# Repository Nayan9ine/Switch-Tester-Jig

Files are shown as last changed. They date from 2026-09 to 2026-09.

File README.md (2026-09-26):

# Switch-Tester-Jig
<div align="right"><i>-by Nayan Ag</i></div>
<br>
Created a switch testing jig using Arduino UNO which tests the electrical durability of contact in scooty switches. 
<br><br>
This is a project that I created during my internship in a 2 wheeler EV startup company. The handle-bar switch assembly are fitted by various switches that the company imports from different vendors. Since it's a startup company we experimented by ordering from different vendors for the same switch. This project was made to test the durability of those.
<br><br>
The various types of switches that were tested are: Horn, Upper-Dipper, Ignition, Reverse.
<br>
Components used: A switch and motor holder,L298N motor controller, two 16X2 I2C LCD, arduino uno, jumper cables,cam to press the button, Switch coupler,12v battery to run motor, Switch for manual control.
<br>
The cam and holder for switches was made by senior.
<br><br>
<table>
  <tr>
    <td>jig
    <br>  <div  align="center"><sub><i> Fig1:Jig with cam and switch installed</i></sub></div>
</td>
    <td>motor holder
    <br>  <div  align="center"><sub><i> Fig2:motor fitting location</i></sub></div>
</td>
    <td>jig switch coupler
    <br><div align="center"><sub><i> Fig3:back side</i></sub></div>
</td>
  </tr>
</table>
<br><br>
<table>
  <tr>
    <td>arduino
    <br>  <div  align="center"><sub><i> Fig4:Arduino UNO</i></sub></div>
</td>
    <td>2 lcds
    <br>  <div  align="center"><sub><i> Fig5:2 LCDs</i></sub></div>
</td>
    <td>battery and switch
    <br><div align="center"><sub><i> Fig6:12v Battery & ON-OFF Switch for manual control</i></sub></div>
</td>
  </tr>
</table>
<br>
<table>
  <tr>
    <td>L298N motor controller
    <br>  <div  align="center"><sub><i> Fig7:Arduino UNO</i></sub></div>
</td>
    <td>switches
    <br>  <div  align="center"><sub><i> Fig8:Switches</i></sub></div>
</td>
    <td>12v motor
    <br><div align="center"><sub><i> Fig9:12v DC Motor</i></sub></div>
</td>
  </tr>
</table>
<br>
<table>
  <tr>
    <td>Switch Pinout
    <br>  <div  align="center"><sub><i> Fig10:Switch Pinout</i></sub></div>
</td>
    <td>overall setup
    <br>  <div  align="center"><sub><i> Fig11:Overall Setup</i></sub></div>
</td>
  </tr>
</table>
<br><br>
Drive link for working video: https://drive.google.com/drive/folders/12oiliMJjxmbsB1hyvkpnEl2Vyk8v8IB5?usp=sharing
<br><br>
<table>
  <tr>
    <td>Sch ERC check
  <br>  <div  align="center"><sub><i> Fig12:Schematic with ERC</i></sub></div>
</td>
    <td>DRC PCB editor Switch Test Jig
    <br>  <div  align="center"><sub><i> Fig13:PCB editor DRC check</i></sub></div>
</td>
    <td>Switch Test Jig PCB editor
    <br>  <div  align="center"><sub><i> Fig14:PCB editor Full view</i></sub></div>
</td>
  </tr>
</table>
<br>
<table>
  <tr>
    <td>3d front switch test
  <br>  <div  align="center"><sub><i> Fig15:3D Front</i></sub></div>
</td>
    <td>3d side switch test
    <br>  <div  align="center"><sub><i> Fig16:3D Side</i></sub></div>
</td>
    <td>3d back switch test
    <br>  <div  align="center"><sub><i> Fig17:3D Back</i></sub></div>
</td>
  </tr>
</table>

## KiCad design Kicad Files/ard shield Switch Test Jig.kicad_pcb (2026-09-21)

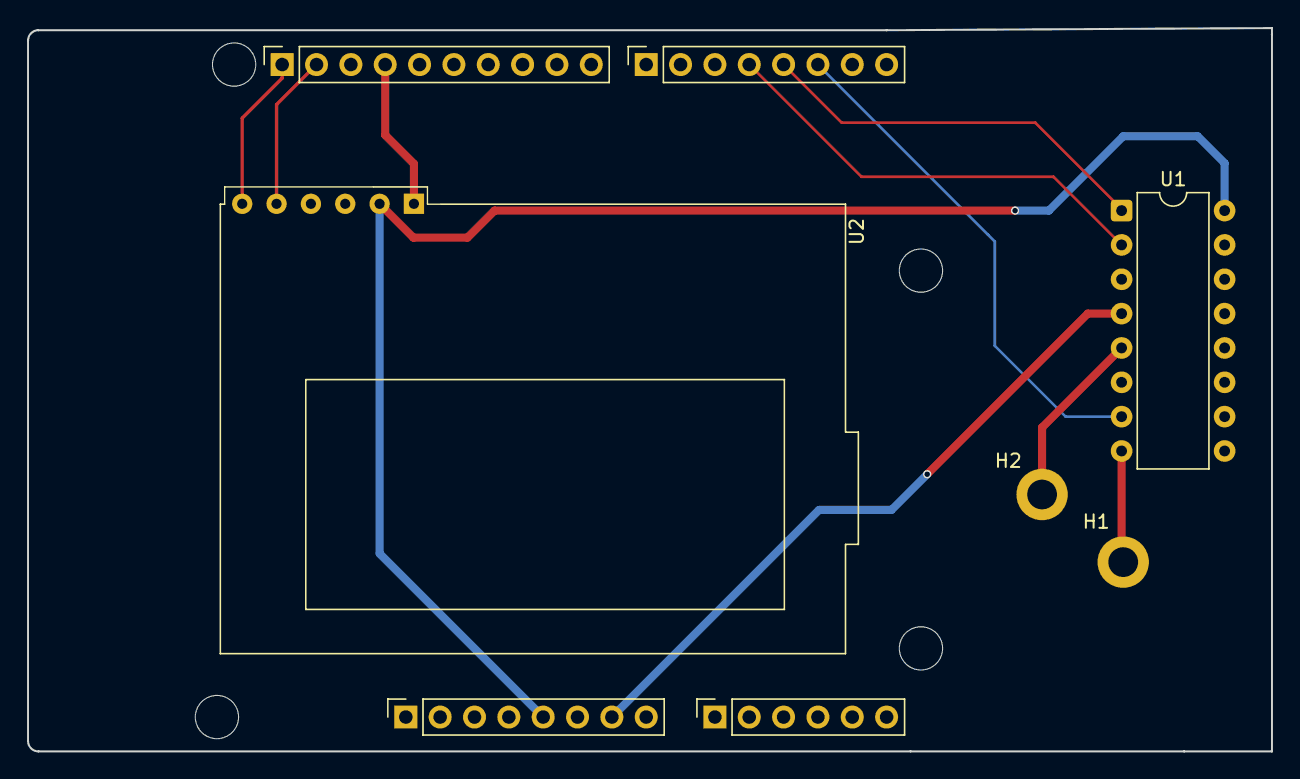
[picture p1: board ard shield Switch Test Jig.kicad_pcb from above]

Board: 2 copper layers, 92.0 x 53.5 mm, 12 parts (0 on the bottom side), 10 nets.

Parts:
H1: +12v; MountingHole_2.2mm_M2_DIN965_Pad
H2: 0v; MountingHole_2.2mm_M2_DIN965_Pad
J1: Power; PinSocket_1x08_P2.54mm_Vertical
J2: Digital/PWM; PinSocket_1x10_P2.54mm_Vertical
J3: Analog; PinSocket_1x06_P2.54mm_Vertical
J4: Digital/PWM; PinSocket_1x08_P2.54mm_Vertical
MH1, MH2, MH3, MH4: MountingHole_3.2mm
U1: L293D; DIP-16_W7.62mm
U2: EA_T123X-I2C

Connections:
/2: J4.6, U1.7 (2A)
/4: J4.4, U1.2 (1A)
/5v: J1.5, U1.16 (VCC1), U2.2 (VDD)
/*3: J4.5, U1.1 (EN1,2)
/SCL/A5: J2.1, U2.6 (SCL)
/SDA/A4: J2.2, U2.5 (SDA)
GND: J1.7, U1.4 (GND)
GND2: J2.4, U2.1 (VSS)
unnamed: H2.1, U1.5 (GND)
unnamed: H1.1, U1.8 (VCC2)

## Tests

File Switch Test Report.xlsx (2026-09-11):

Switch Test Report
Report No: |  |  | Report Date: |  | 2024-04-08
Report Revision |  | 1 | Prepared By: |  | Nayan
Subject | Endurance testing of Switch
Objective | Testing the number of times the switch works properly till failure
Test Procedure Detail
A switch is put in the testing jig and the switches are pressed at frequency of 10,814 for Horn and 11064 for upper/dipper per hour and Horn and up/dip was run for 12 hrs whereas reverse was run for 10 hrs. As soon as the number of clicks surpassed the target the test was considered to be successful.
SWITCH TYPE |  | VENDOR NAME |  | USAGE
Upper-Dipper |  |  |  | Used to change headlight beam direction -Upper mode used in long range to increase visibility -Dipper mode used to avoid glaring
Horn |  |  |  | Auditory warning to alert the other vehicles of your presence
Reverse |  |  |  | Used to put the vehicle in reverse mode
MODE 1 |  |  |  | ECO mode
MODE 3 |  |  |  | POWER mode
TARGET: 1lakh clicks per switch
Observation/Result
SWITCH |  | NO. OF CLICKS |  | FREQUENCY (per hr) |  | REMARK
Horn |  | 1,32,841 |  | 10814 |  | parameters met
Upper |  | 89573 |  | 11064 |  | switch stopped responding to machine press as it's connections became soft but still works when pressed manually
Dipper |  | 1,32,724 |  | 16393 |  | Parameters met
Reverse |  | 1,24,047 |  | 12570 |  | parameters met
Mode 3 |  | 54216 |  | 5672 |  | Switch deformed but still works (not workable with jig)
Mode 1 |  | 40999 |  | 4795
OFF
DRL
HI-BEAM
CONCLUSION
The testing of the switch was done and the required goal parameters were succesfully met with the exception of upper switch. and mode switch

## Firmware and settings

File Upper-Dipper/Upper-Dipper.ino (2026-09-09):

#include <Wire.h>
#include <LiquidCrystal_I2C.h>

//L298N MOTOR DRIVER pins
#define enA 5
#define in1 2
#define in2 3

//upper switch
const byte switchPin1 = 4;
//variables needed to detect switch press
byte switchState1 = LOW;
byte lastSwitchState1 = LOW;
unsigned long counter1 = 0;              //stores switch press number
unsigned long lastDebounceTime1 = 0;
unsigned long debounceDelay1 = 50;
//variables needed for flashing function
unsigned long lastCounterChangeTime1 = 0;
unsigned long flashingInterval1 = 5000;  // Set the interval for flashing in milliseconds

//dipper switch
const byte switchPin2 = 6;  
byte switchState2 = LOW;
byte lastSwitchState2 = LOW;
unsigned long counter2 = 0;
unsigned long lastDebounceTime2 = 0;
unsigned long debounceDelay2 = 50;
unsigned long lastCounterChangeTime2 = 0;
unsigned long flashingInterval2 = 5000;  

//LCD initialization
LiquidCrystal_I2C lcd(0x27, 16, 2);
//by deafult not flashing
bool isFlashing1 = false;
bool isFlashing2 = false;
unsigned long lastFlashTime1 = 0;
unsigned long lastFlashTime2 = 0;

void setup() {
  lcd.init();
  lcd.setBacklight(255);
  lcd.print("Up : ");
  lcd.setCursor(0, 1);
  lcd.print("Dip: ");
  // Serial.begin(9600);
  /*Using digital pin as INPUT makes arduino connect that pin to a large resistor value so it takes very minimal current,
  hence no risk of pin burning*/
  pinMode(switchPin1, INPUT);
  pinMode(switchPin2, INPUT);
  //motor config
  pinMode(enA, OUTPUT);
  pinMode(in1, OUTPUT);
  pinMode(in2, OUTPUT);
  // pinMode(button, INPUT);
  // Set initial rotation direction =stopped
  pinMode(in1,LOW);
  pinMode(in2,LOW);
  analogWrite(enA,180);
}

void loop() {
  //motor in anticlockwise direction 
  digitalWrite(in1, LOW);
  digitalWrite(in2, HIGH);

  unsigned long currentMillis = millis();
  //loop to handle flashing 
  if ( ((currentMillis - lastCounterChangeTime1) > flashingInterval1) || ((currentMillis - lastCounterChangeTime2) > flashingInterval2)) {
    if (!isFlashing1 || !isFlashing2) {
      isFlashing1 = true;
      isFlashing2 = true;

      lastFlashTime1 = currentMillis;
      lastFlashTime2 = currentMillis;
      }
    //flashing starts,used millis() to avoid using delay which stops entire processing  
    if ((currentMillis - lastFlashTime1) < 500 || (currentMillis - lastFlashTime2) < 500 ) {
      lcd.setBacklight(255);  // Turn backlight on
    } else if ((currentMillis - lastFlashTime1) < 1000 || (currentMillis - lastFlashTime2) < 1000 ) {
      lcd.setBacklight(0);    // Turn backlight off
    } else {
      lastFlashTime1 = currentMillis;
      lastFlashTime2 = currentMillis;
    }
  }
   
  else {
    isFlashing1 = false;
    isFlashing2 = false;
    lcd.setBacklight(255);  // Turn backlight on
  }
  // Handle switch input and counter 1
  byte reading1 = digitalRead(switchPin1);
  if (reading1 != lastSwitchState1) {
    lastDebounceTime1 = currentMillis;
  }
  if ((currentMillis - lastDebounceTime1) > debounceDelay1) {
    if (reading1 != switchState1) {
      switchState1 = reading1;
      if (switchState1 == HIGH) {
        counter1++;
        lastCounterChangeTime1 = currentMillis;  // Update the time of the last counter change
        // lcd.setCursor(6, 0);  // Position for Counter1
        // lcd.print("      ");  // Clear the area
        lcd.setCursor(6, 0);
        lcd.print(counter1);
      }
  }
  }
  lastSwitchState1 = reading1;

  // Handle switch input and counter 2
  byte reading2 = digitalRead(switchPin2);
  if (reading2 != lastSwitchState2) {
    lastDebounceTime2 = currentMillis;
  }
  if ((currentMillis - lastDebounceTime2) > debounceDelay2) {
    if (reading2 != switchState2) {
      switchState2 = reading2;
      if (switchState2 == HIGH) {
        counter2++;
        lastCounterChangeTime2 = currentMillis;  // Update the time of the last counter change
        lcd.setCursor(6, 1);  // Position for Counter2
        lcd.print("      ");  // Clear the area
        lcd.setCursor(6, 1);
        lcd.print(counter2);
      }
    }
  }
  lastSwitchState2 = reading2;
}

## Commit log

2026-09-11 Add files via upload
    Report with sensitive info blurred made during internship.
    [Switch Test Report.xlsx]
2026-09-21 Create Kicad Files
2026-09-21 Create Switch test Jig
